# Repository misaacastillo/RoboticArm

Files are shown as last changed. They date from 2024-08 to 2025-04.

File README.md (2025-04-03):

# ROBOTIC ARM

“Robotic Arm” es un brazo robotico el cual cuenta con un modelo dummy de menores dimensiones.
Este modelo copia tendrá una conexión entre sus potenciómetros y los servomotores ubicados en el modelo principal.
Al mover con la mano las 4 articulaciones del modelo dummy provocará que el modelo original se mueva por su cuenta y en sincronía. 
Además el modelo dummy contará con un botón en el extremo superior del brazo, el cual al ser presionado, accionará la pinza ubicada en el extremo superior del modelo original. 

## BRAZO PRINCIPAL:

Robotic arm original

## MODELO DUMMY:

Robotic Arm dummy

## Contacto
### Misael Castillo
* 📷 Instagram: [@misaacas](https://www.instagram.com/misaacas/)
* 📧 Mail: misacastillo08@gmail.com
* 🏆 LinkedIn: [Castillo Misael](https://www.linkedin.com/in/misael-castillo-0a52a1314/)
* 🌐 Github: [misaacastillo](https://github.com/misaacastillo)

## 📜 Licencia

Este proyecto está licenciado bajo la [MIT License](LICENSE).  
© 2024 Robotic Arm By Misael Castilo

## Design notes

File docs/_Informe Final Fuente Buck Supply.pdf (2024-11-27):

EEST N°7 - Computadoras y Sistemas de Control - Profesor Carlassara Fabrizio

## ANTEPROYECTO DE “TÍTULO DEL PROYECTO”

Integrante 1: Castillo Misael

Integrante 2: Bianco Tomas

Integrante 3: Somoza Juan Cruz

Integrante 4: Ramirez Santino

## 1. INTRODUCCIÓN

Este proyecto consiste en el diseño y desarrollo de una fuente de alimentación reductora tipo buck, capaz de transformar una entrada de 220V AC en una salida regulada de 5V DC a 6A. Su diseño incluye etapas de protección, rectificación y regulación, controladas por un microcontrolador RP2040. Esta fuente garantiza una salida estable y eficiente, adecuada para alimentar dispositivos electrónicos que requieren un suministro constante de energía.
El sistema está diseñado para alimentar un brazo robótico que replica movimientos de forma precisa. El brazo principal, equipado con servos en sus articulaciones, se sincroniza con un brazo más pequeño mediante potenciómetros, permitiendo que este último actúe como controlador manual. De esta forma, el proyecto combina una fuente de alimentación confiable con un sistema de robótica interactiva que puede aplicarse en diversas áreas tecnológicas y educativas.

## 2. MARCO DE APLICACIÓN

El marco de aplicación de este proyecto abarca diversas áreas relacionadas con la robótica, la automatización y la electrónica de control. Algunas de las principales áreas o campos en los que podría utilizarse son:

1. Robótica Industrial: Este diseño podría ser utilizado para el control preciso de brazos robóticos en líneas de ensamblaje o procesos automatizados en fábricas, donde la repetición exacta de
movimientos es crucial.
2. Prototipos de Robots
Asistenciales: El brazo robótico replicador puede servir como base para dispositivos en áreas médicas o de rehabilitación, como prótesis robóticas o exoesqueletos, donde es necesario sincronizar
movimientos entre dispositivos.
3. Educación y Capacitación: Este sistema puede ser utilizado en instituciones educativas como herramienta para enseñar
conceptos de control de motores, diseño de fuentes de alimentación, y electrónica de potencia.
4. Robótica de precisión: En laboratorios o centros de
investigación, el brazo podría aplicarse en tareas delicadas que requieren replicación exacta de movimientos, como manipulación de muestras o ensamblaje de componentes pequeños.

## 3. DESCRIPCIÓN TÉCNICA

El proyecto consiste en el diseño de una fuente reductora tipo buck que convierte una entrada de 220V AC en una salida regulada de 5V DC a 6A. El circuito incluye una etapa de protección con fusible, varistor y un puente rectificador (KBU6M) que convierte la señal AC en DC, la cual se filtra mediante un condensador para reducir el ripple. La etapa de regulación utiliza un MOSFET (IRF840N) controlado por una señal PWM generada por el microcontrolador RP2040 Zero. Un inductor se lleva una parte de la tensión de entrada y un diodo Schottky (MBR745) para que la corriente tenga un camino cuando el MOSFET se encuentre NO SATURADO, mientras que un condensador adicional filtra la salida, proporcionando un voltaje constante y estable. El MOSFET está protegido por un diodo zener conectado entre gate y source.
El RP2040 ajusta el ciclo de trabajo del PWM tomando una muestra de la salida mediante un divisor resistivo, que es procesada por el ADC y comparada con una referencia. Si el voltaje de salida está por debajo de la referencia, aumenta el ciclo de trabajo; si está por encima, lo reduce, asegurando así una regulación precisa. Además, se incluye una etapa de pre-amplificación con transistores BC548 para garantizar la correcta conmutación del MOSFET. Este diseño busca mantener una salida estable de 5V DC a pesar de variaciones en la carga o en la entrada.
Esta fuente alimenta un brazo robótico que cuenta con 4 servos, uno en cada articulación del brazo principal de mayor dimensión. Además, hay un brazo más pequeño que tiene un potenciómetro en cada articulación, y estos potenciómetros están conectados a las correspondientes articulaciones del brazo grande. Esto permite que al mover manualmente el brazo pequeño, el brazo grande copie fielmente los movimientos, facilitando el control preciso de las articulaciones mediante la relación directa entre los potenciómetros y los servos.

### 3.1 SOBRE EL HARDWARE

A continuación se adjunta un diagrama en bloques para comprender de manera más sencilla la composición del hardware:

- https://github.com/user-attachments/assets/36affe4c-1349-4181-a6b1-dc6996a2df79 (https://github.com/user-attachments/assets/36affe4c-1349-4181-a6b1-dc6996a2df79)

### 3.2 SOBRE EL SOFTWARE

A continuación se adjunta un diagrama en bloques para comprender la logica del código implementado:

- https://github.com/user-attachments/assets/fa563f7c-4881-4cb9-95a1-9199d777e7dc (https://github.com/user-attachments/assets/fa563f7c-4881-4cb9-95a1-9199d777e7dc)

## 4. DIVISIÓN DE TAREAS

### 4.1 INTEGRANTE 1

Hardware y software

### 4.2 INTEGRANTE 2

Hardware

### 4.3 INTEGRANTE 3

Hardware

### 4.4 INTEGRANTE 4

Hardware

## 5. LISTA DE MATERIALES

### 1. Componentes de la etapa de

entrada y protección

- F1: Fusible 6A
- RV1: Varistor
- D1: Puente de diodos rectificadores (KBU6M)
- C2: Condensador de filtrado 450v 100uf

### 2. Componentes de la etapa buck

- Q1: MOSFET IRF840N
- L1: Inductor (12uH)
- D3: Diodo Schottky (MBR745)
- C1: Condensador de salida (25v 330uf)
- D2: Diodo zener para protección del MOSFET (12v 1w)

- R2 y R3: Resistencias (2k2 1/4w - 6k8 1/4w)

### 3. Controlador PWM y disparo del MOSFET

- RP2040 Zero: Microcontrolador
- R1: Resistencia pull-down (valor no especificado)
- Q2 y Q3: Transistores bipolares BC548
- R4, R5, R6, R7: Resistencias asociadas al control del disparo del MOSFET (47omh, 470omh 1komh)
- C3: Condensador de filtrado del transformador (2200uf 16v)
- D4: Diodo rectificador (1N4007)
- Transformador 12v

### 4. Salidas

- Conectores terminales para servos y alimentación (etiquetados como S0, S1, S2, S3, y sus respectivas conexiones GND y Vout).
- Servos MG946r, SG90.

## 6. IMAGENES DE AVANCES

- PCB
https://github.com/user-attachments/assets/a5d8c636-becd-42a4-9ac3-93294eef8 122 (https://github.com/user-attachments/assets/a5d8c636-becd-42a4-9ac3-93294eef8122)
- Esquematico:
https://github.com/user-attachments/assets/1181bec4-19ed-48ac-91b0-94e42b19 c853 (https://github.com/user-attachments/assets/1181bec4-19ed-48ac-91b0-94e42b19c853)
- Avances:
- https://github.com/user-attachments/assets/632c705f-0e87-40a1 -9880-3bf0f9fe2a5b (https://github.com/user-attachments/assets/632c705f-0e87-40a1-9880-3bf0f9fe2a5b)
- https://github.com/user-attachments/assets/e3903cf5-bc35-4578 -b635-476c0d83b1fa (https://github.com/user-attachments/assets/e3903cf5-bc35-4578-b635-476c0d83b1fa)
- https://github.com/user-attachments/assets/97ad6955-29c6-469a -9932-acfbd8ea4d8d (https://github.com/user-attachments/assets/97ad6955-29c6-469a-9932-acfbd8ea4d8d)

## 7. MEDICIONES REALIZADAS

Se realizaron múltiples mediciones para verificar el funcionamiento de la fuente buck. Inicialmente, se colocó un transformador de 35V en la entrada del circuito. El primer paso fue probar el disparo del MOSFET, para lo cual se conectó a tierra (GND) el pin destinado al control PWM del microcontrolador. Durante esta prueba, se verificó que el MOSFET saturaba correctamente, lo que indicaba que estaba funcionando de acuerdo con lo esperado.

Una vez comprobado el correcto funcionamiento del MOSFET, se procedió a cargar el código en el microcontrolador RP2040. La lógica del código consiste en utilizar el ADC para leer un voltaje de la salida del circuito y compararlo con un voltaje de referencia. Si el voltaje de salida estaba por debajo del valor de referencia, el código aumentaba el ciclo de trabajo del PWM para incrementar el voltaje de salida. Por otro lado, si el voltaje de salida supera el valor de referencia, el ciclo de trabajo se reducía para disminuir el voltaje de salida.

Para realizar la práctica y verificar este comportamiento, se utilizó una fuente de laboratorio conectada al ADC del microcontrolador. Mediante la perilla de ajuste fino de la fuente, se variaba el voltaje entre 0V y 3.3V con precisión. Al realizar esta variación, se observó que el voltaje de salida del circuito respondía adecuadamente al ajuste del ciclo de trabajo generado por el microcontrolador.

Sin embargo, se detectó un problema crítico: al saturar el MOSFET, la tensión de entrada aparecía momentáneamente en la salida. Este comportamiento representaba un fallo grave en el diseño de la fuente buck.

## 8. CONCLUSIÓN FINAL

En conclusión, aunque se logró implementar la lógica de control y se verificó su funcionamiento en términos de ajuste de la salida, el problema identificado con la tensión de entrada en la salida durante la saturación del
MOSFET marcó el final del desarrollo de esta fuente buck. A pesar de no poder lograr el correcto funcionamiento de este circuito, durante el proceso se ha podido aprender mucho sobre electrónica de potencia y la implementación de un microcontrolador en este ámbito.

## 9. Repositorio GITHUB

https://github.com/misaacastillo/RoboticArm

## 9. REFERENCIAS

Agregar cualquier referencia que se haya usado durante la investigación o el informe.

[1] Referencia 1. Disponible en: https://datasheets.raspberrypi.com/pico/raspberry-pi -pico-c-sdk.pdf (https://datasheets.raspberrypi.com/pico/raspberry-pi-pico-c-sdk.pdf)
[2] Referencia 2. Disponible en: https://www.youtube.com/watch?v=AIsVlgopqJc&t=480s&ab_channel=BuildSomeStuff (https://www.youtube.com/watch?v=AIsVlgopqJc&t=480s&ab_channel=BuildSomeStuff)
[3] Referencia 3. Disponible en: https://www.academia.edu/11237823/ELECTR%C3

%93NICA_DE_POTENCIA_ELECTR%C3%93NICA _DE_POTENCIA (https://www.academia.edu/11237823/ELECTR%C3%93NICA_DE_POTENCIA_ELECTR%C3%93NICA_DE_POTENCIA)

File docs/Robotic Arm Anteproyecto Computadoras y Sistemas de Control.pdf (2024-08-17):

EEST N°7 - Computadoras y Sistemas de Control - Profesor Carlassara Fabrizio

ANTEPROYECTO DE “ROBOTIC ARM”

Integrante 1: Castillo Misael Integrante 1: correo electrónico: misaelcastillo@impatrq.com Integrante 2: Bianco Tomas Integrante 2: correo electrónico: tomasmartinbianco@impatrq.com Integrante 3: Somoza Juan Cruz Integrante 3: correo electrónico:juancruzarielsomoza@impatrq.com Integrante 4: Tolosa Ramirez Santino Integrante 4: correo electrónico: santinoramireztolosa@impatrq.com

### 1. INTRODUCCIÓN

“Robotic Arm” es un brazo robótico el cual cuenta con un modelo dummy de menores dimensiones. Este modelo copia tendrá una conexión entre sus potenciómetros y los servomotores ubicados en el modelo principal. Al mover con la mano las 4 articulaciones del modelo dummy provocará que el modelo original se mueva por su cuenta y en sincronía. Además el modelo dummy contará con un botón en el extremo superior del brazo, el cual al ser presionado, accionará la pinza ubicada en el extremo superior del modelo original.

### 2. MARCO DE APLICACIÓN

### 2.1 BRAZO ROBÓTICO

Este proyecto tiene una gran variedad de aplicaciones. Una de ellas podría ser en el área de la medicina. En el caso que se presentará un paciente con una enfermedad contagiosa de alto riesgo, se podría instalar el modelo original en un cuarto aislado y el modelo dummy en el exterior. Así los enfermeros o médicos podrían atender a las necesidades del paciente sin contagiarse.
También este brazo robótico podría participar en cirugías asistidas.
Otro campo de aplicación posible es en la educación. Se podría instalar el modelo principal en el pizarrón de la clase y el modelo dummy en el escritorio del profesor. Este podría escribir en el pizarrón con mayor comodidad y mayor eficiencia.

### 2.2 FUENTE TIPO SWITCHING

Las fuentes de alimentación tipo switching o fuentes conmutadas son muy versátiles y se utilizan en una variedad de aplicaciones debido a su alta eficiencia, tamaño compacto y capacidad para manejar una amplia gama de voltaje de entrada. Estas mismas se pueden encontrar en:
1. dispositivos electrónicos
Son esenciales en una amplia gama de dispositivos. como por ejemplo computadoras, teléfonos y sistemas de comunicación
2. aplicaciones industriales y comerciales
3. dispositivos portátiles y electrónica de consumo
Son compactas y ligeras, lo que las hace ideal para aplicaciones en donde el espacio es limitado
4. máquinas y procesos

### 3. DESCRIPCIÓN TÉCNICA

Se debe realizar una descripción de cada uno de los componentes que se planea usar para este proyecto. Incluir qué variables se estarán monitoreando mediante el sistema de control.

1- Fuente conmutada:

Una fuente conmutada usa la señal de control para variar el ancho de pulso, tomando de la alimentación solamente la energía requerida por la carga.

2- Modelo Dummy:
Este es un modelo a escala del brazo robótico principal. Tiene 4 articulaciones que pueden moverse manualmente. Cada articulación está equipada con un potenciómetro que mide el ángulo de la articulación.

3- Potenciómetros:
Estos son sensores que miden el ángulo de las articulaciones en el modelo dummy. Cuando mueves una articulación en el modelo dummy, el potenciómetro correspondiente produce una señal eléctrica proporcional al ángulo de la articulación.

4- Servomotores:
Estos están ubicados en el brazo robótico principal. Cada servomotor está conectado a un potenciómetro en el modelo dummy. Cuando el potenciómetro detecta un cambio en el ángulo de una articulación, envía una señal al servomotor correspondiente para mover la articulación en el brazo robótico principal.

5- Pinza:
Está ubicada en el extremo superior del brazo robótico principal. Se activa cuando se presiona un botón en el extremo superior del modelo dummy.

Las variables que se estarán monitoreando incluyen:

1- Ángulos de las articulaciones: Estos son medidos por los potenciómetros en el modelo dummy. Estos ángulos son las variables de entrada para el sistema de control.

2- Posición de la pinza: Esta es una variable binaria que indica si la pinza está abierta o cerrada. Se activa cuando se presiona el botón en el modelo dummy

3- fuente conmutada: En el caso de la fuente conmutada, utiliza el sistema de comunicación denominado “modulación por ancho de pulso” (PWM) y la variable a monitorear es:

- Tensión de salida (Vout): Es fundamental monitorear esta variable para garantizar que la tensión de salida se mantenga dentro de los límites especificados. Esta variable será introducida por una entrada del microcontrolador ADC (analog to digital converter) y será monitoreada por nuestro microcontrolador. Cuando el ADC muestre una lectura del voltaje de salida errónea automáticamente el microcontrolador adaptará el ancho de pulso del PWM para corregir la tensión de salida

### 3.1 SOBRE EL HARDWARE

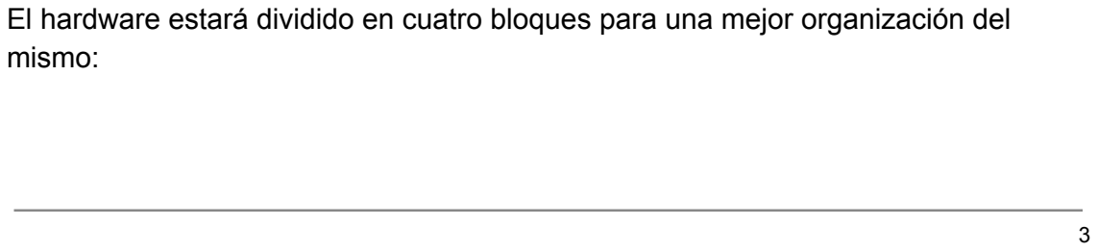
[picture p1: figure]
mismo:

El hardware estará dividido en cuatro bloques para una mejor organización del

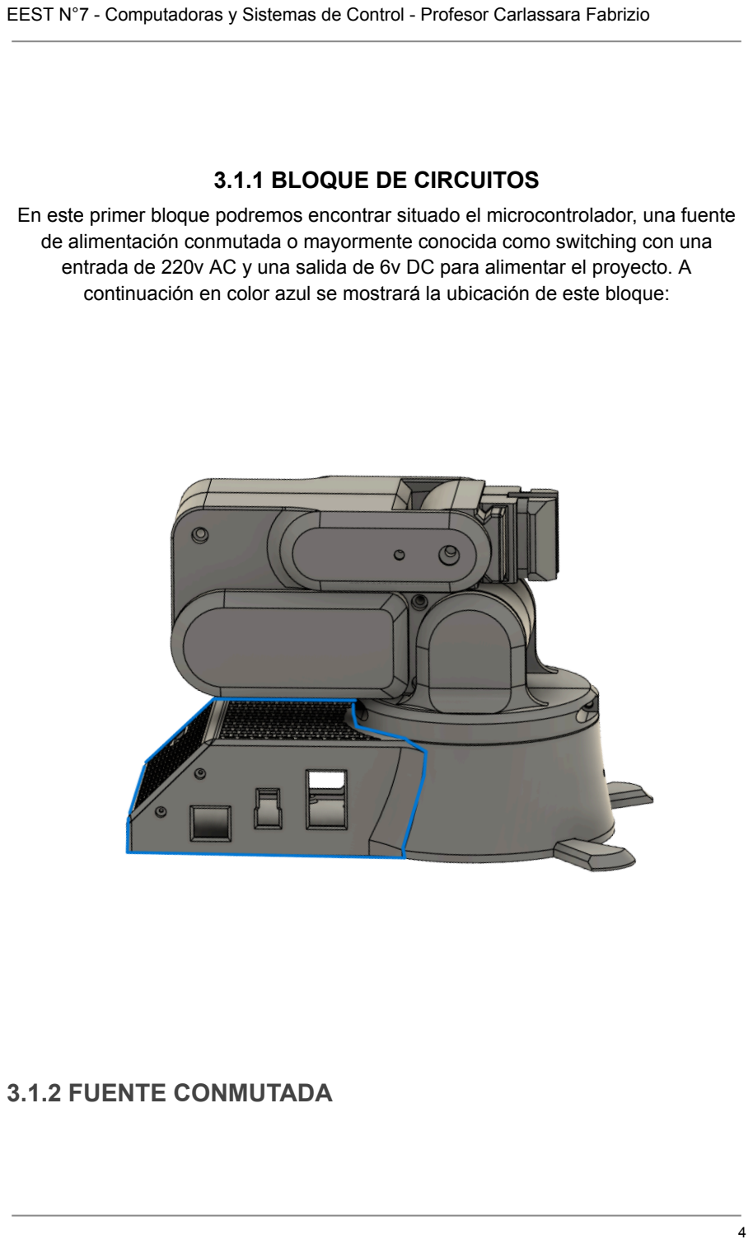
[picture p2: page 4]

### 3.1.1 BLOQUE DE CIRCUITOS

En este primer bloque podremos encontrar situado el microcontrolador, una fuente de alimentación conmutada o mayormente conocida como switching con una entrada de 220v AC y una salida de 6v DC para alimentar el proyecto. A continuación en color azul se mostrará la ubicación de este bloque:

### 3.1.2 FUENTE CONMUTADA

- Entrada Ac
- Puente rectificador: Un puente rectificador consta de cuatro diodos conectados en una configuración específica. En una disposición típica, dos diodos se conectan en serie en una dirección, y otros dos diodos se conectan en serie en la dirección opuesta. Esto crea una estructura en forma de puente. La corriente alterna (CA) de la red eléctrica se rectifica para convertirla en corriente continua (CC)
- Condensador: Amortigua la corriente pulsante para convertirla en corriente continua con un valor estable
- Conmutación: Un dispositivo semiconductor, que generalmente es un MOSFET, se utiliza para alternar rápidamente entre un estado de conducción completo (encendido) y un estado de corte completo (apagado). Este proceso de conmutación se controla para regular la cantidad de energía que se entrega a la carga.
- Controlador: Activa y desactiva el transistor. También controla al circuito de corrección del factor de potencia. Además, mide la tensión de salida de la fuente, y modifica la señal entregada al transistor, para regular la tensión y mantener estable la salida
- Bobina: Durante el ciclo de conmutación, la energía almacenada en un inductor se transfiere a la carga. La relación entre el tiempo que el dispositivo está encendido y apagado controla la cantidad de energía entregada.
- Diodo: Convierte la corriente alterna del transformador a corriente pulsante.
- Filtro: Convierte la corriente pulsante en continua.

### 3.1.3 BLOQUE ROTOR 180’

En este bloque estará ubicado un servomotor el cual le dará la capacidad a la mano robótica de poder realizar un giro de 360°. A continuación en color rojo se mostrará la ubicación de este bloque:

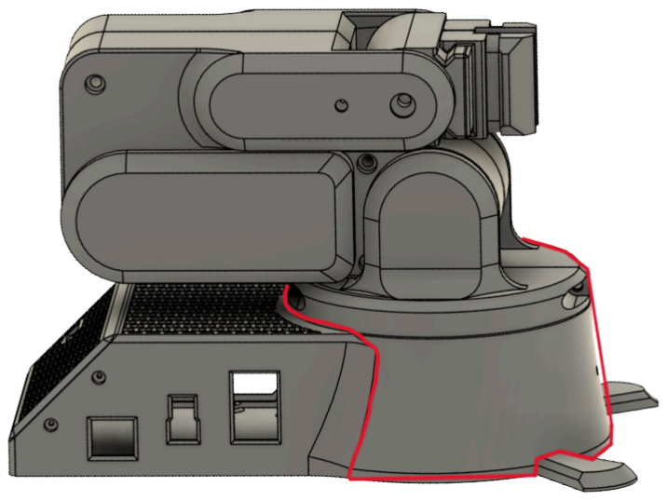
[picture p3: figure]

### 3.1.4 BLOQUE ARTICULACIONES

En este bloque se encuentran los servo motores encargados de articular el brazo robótico. A continuación en color naranja se mostrará la ubicación de este bloque:

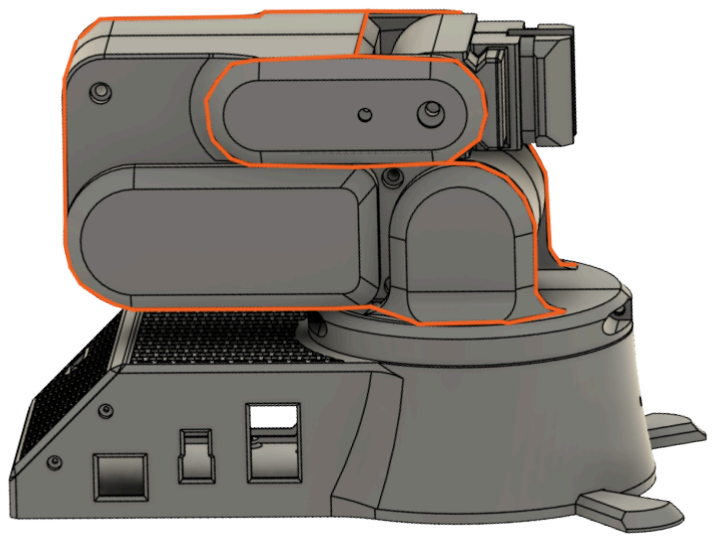
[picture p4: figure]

### 3.1.5 BLOQUE PINZA

Por último en este bloque se encontrará el servo encargado de abrir y cerrar esta pinza. A continuación en color naranja se mostrará la ubicación de este bloque:

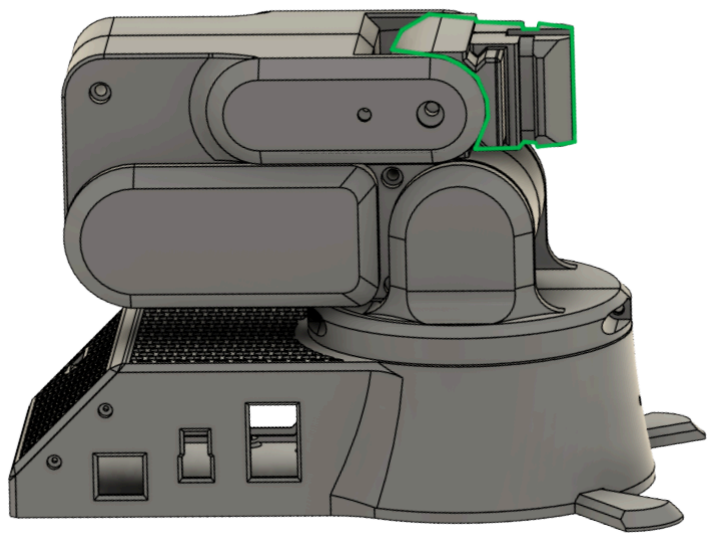
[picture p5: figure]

ACLARACIÓN: ESTE ES UN BOCETO DE DISEÑO, A FUTURO SE REALIZARÁN MODIFICACIONES PARA MEJORAR SU ESTÉTICA Y OPTIMIZAR LA DISTRIBUCIÓN DE CIRCUITOS.

### 3.2 SOBRE EL SOFTWARE

- Lectura de datos: Implementar un código que lea los datos de los potenciómetros en el modelo dummy. Estos datos representan los ángulos de las articulaciones y se utilizarán para controlar los servomotores en el brazo robótico principal.
- Control de servomotores: Desarrollar un algoritmo que tome los datos de los potenciómetros y los convierta en señales de control para los servomotores. Este algoritmo debe asegurarse de que los movimientos del brazo robótico principal estén sincronizados con los del modelo dummy.
- Control de la pinza: Implementar un código que detecte cuando se presiona el botón en el modelo dummy y active la pinza en el brazo robótico principal.
- Pruebas y depuración: Realizar pruebas exhaustivas para asegurarse de que el software funciona correctamente. Esto incluirá pruebas unitarias de cada componente individualmente, así como pruebas de integración para verificar que todos los componentes funcionen juntos como se espera.

### 4. DIVISIÓN DE TAREAS

Detallar las tareas asignadas a cada integrante del equipo.

### 4.1 INTEGRANTE 1

- software (codigo), estructura en 3D

### 4.2 INTEGRANTE 2

- software (codigo)

### 4.3 INTEGRANTE 3

- Hardware (conexiones) , ensamblaje

### 4.4 INTEGRANTE 4

- Hardware (alimentación)

### 5. LISTA DE MATERIALES

A-Mg946r Servo Motor x 4
B-Mini Servo Tower Pro Sg90 x1 C-Fuente switching
D-Impresiones en 3D
E-Potenciómetros 10k x3
F-Raspberry pi pico

### 5. REFERENCIAS

Agregar cualquier referencia que se haya usado durante la investigación o el informe.

[1] Referencia 1. Disponible en: https://www.youtube.com/watch?v=5toNqaGsGYs&ab_channel=BuildSomeStuff

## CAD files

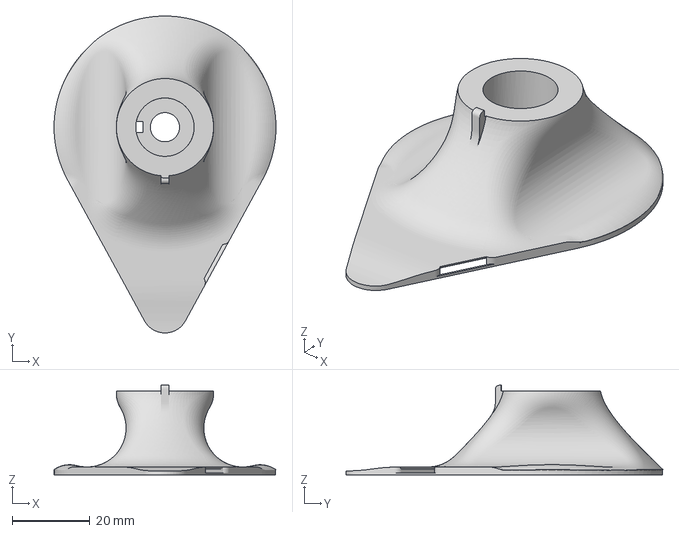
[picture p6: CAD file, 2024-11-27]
mechanical/Piezas 3D 2/Cuerpo1.3mf
57.0 x 81.4 x 23.0 mm

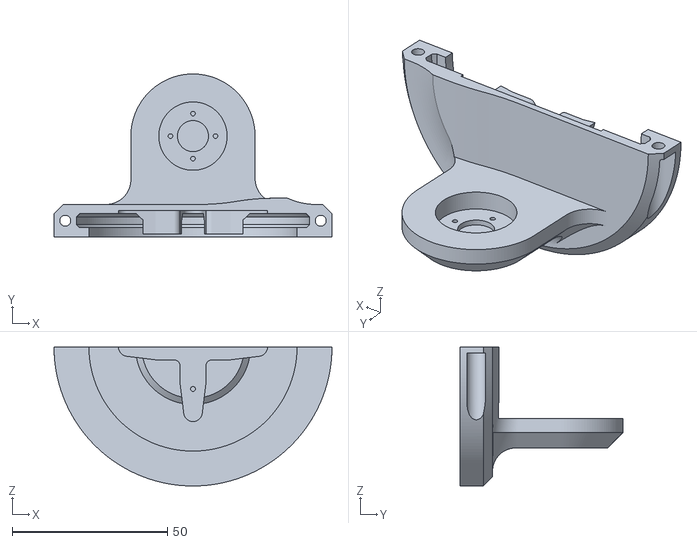
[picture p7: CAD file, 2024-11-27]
mechanical/Piezas 3D/Cuerpo7.stl
89.5 x 52.5 x 44.7

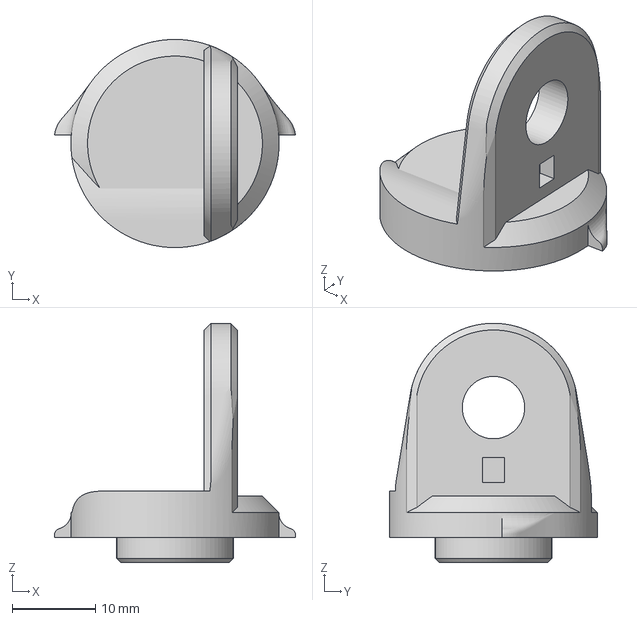
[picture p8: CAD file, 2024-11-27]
mechanical/Piezas 3D 2/Cuerpo2.3mf
28.9 x 25.0 x 28.7 mm

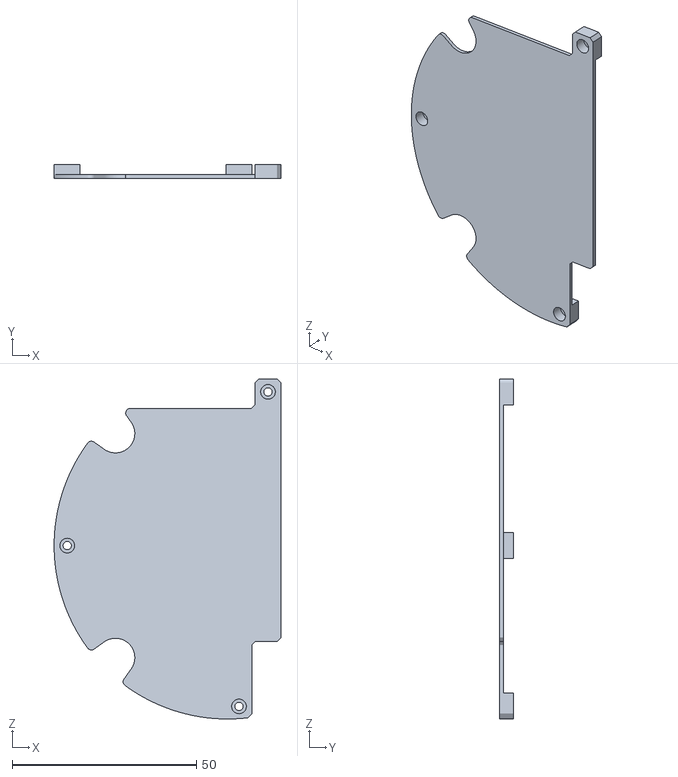
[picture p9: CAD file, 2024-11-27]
mechanical/Piezas 3D/Cuerpo12.stl
61.6 x 3.75 x 92.4

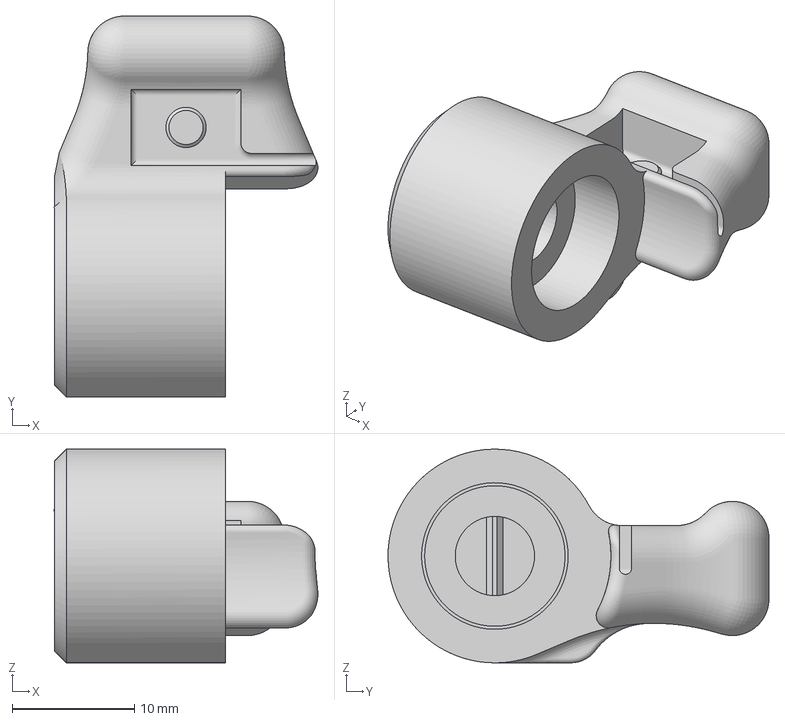
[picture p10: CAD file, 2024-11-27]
mechanical/Piezas 3D 2/Cuerpo5.3mf
21.6 x 31.2 x 17.5 mm

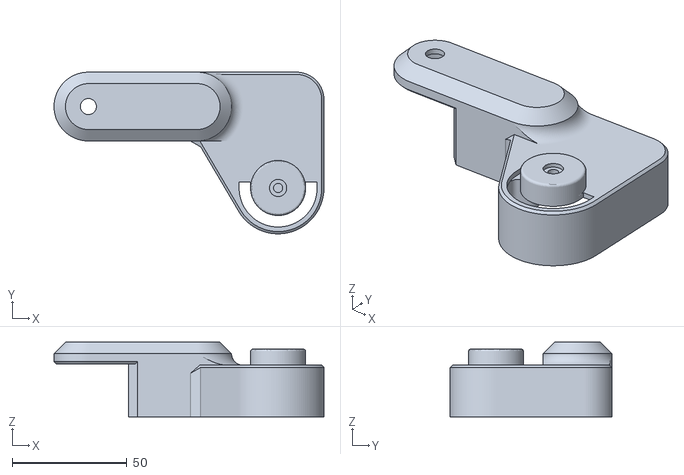
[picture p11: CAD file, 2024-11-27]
mechanical/Piezas 3D/Cuerpo2.stl
117.7 x 70.5 x 32.5

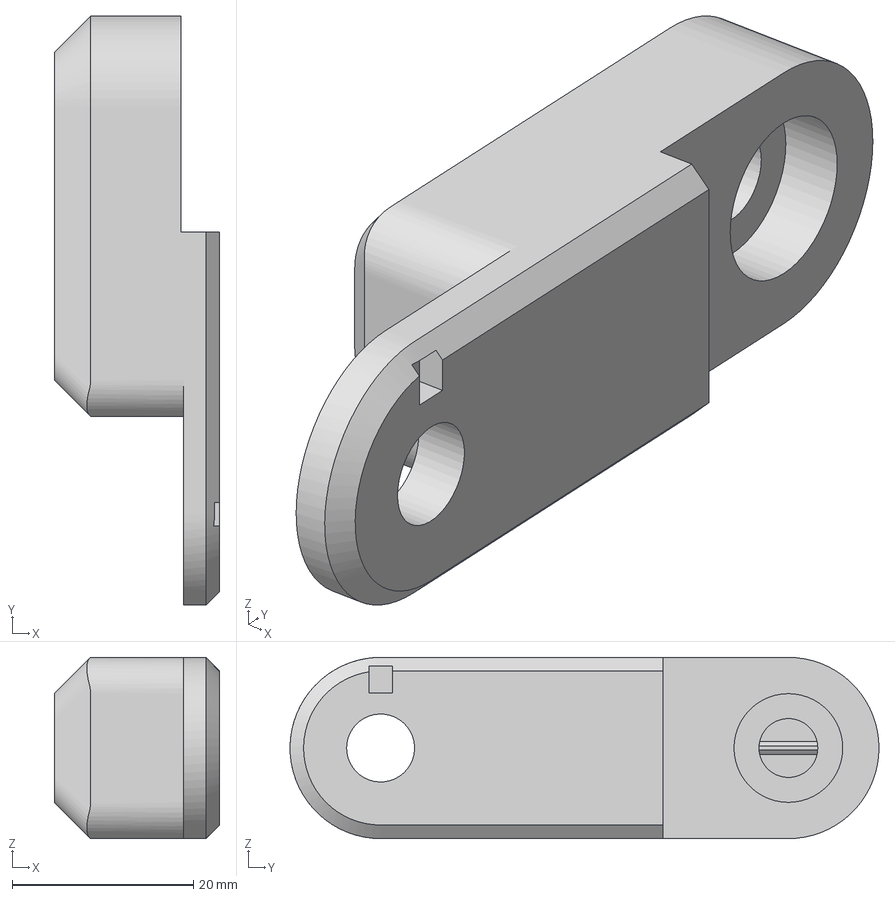
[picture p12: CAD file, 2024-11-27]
mechanical/Piezas 3D 2/Cuerpo3.3mf
18.2 x 65.0 x 20.0 mm

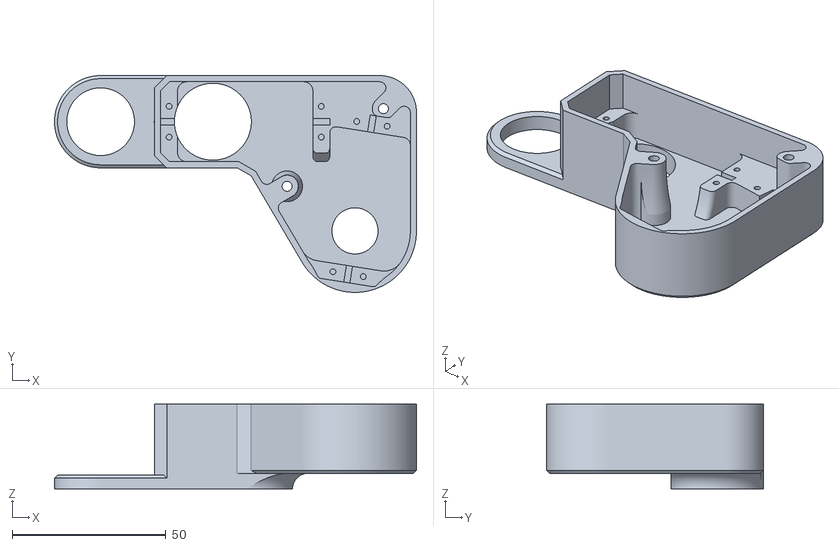
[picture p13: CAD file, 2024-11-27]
mechanical/Piezas 3D/Cuerpo8.stl
117.7 x 70.5 x 27.5

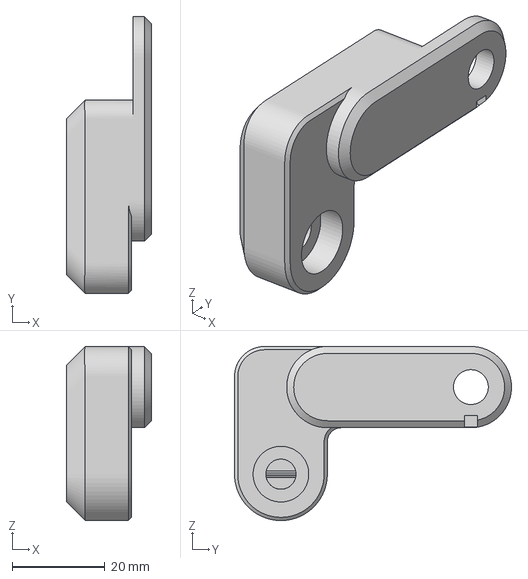
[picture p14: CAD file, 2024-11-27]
mechanical/Piezas 3D 2/Cuerpo4.3mf
18.2 x 59.6 x 37.5 mm

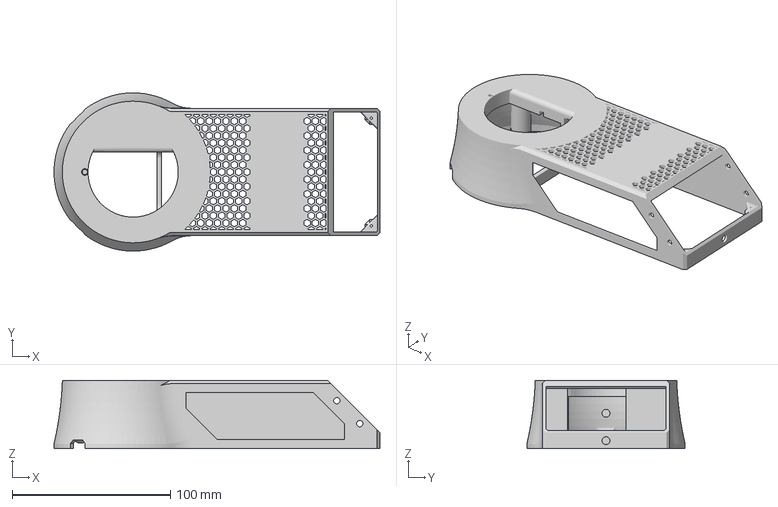
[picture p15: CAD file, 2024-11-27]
mechanical/Piezas 3D/Estructura inf fuente.3mf
206.0 x 100.0 x 43.0 mm

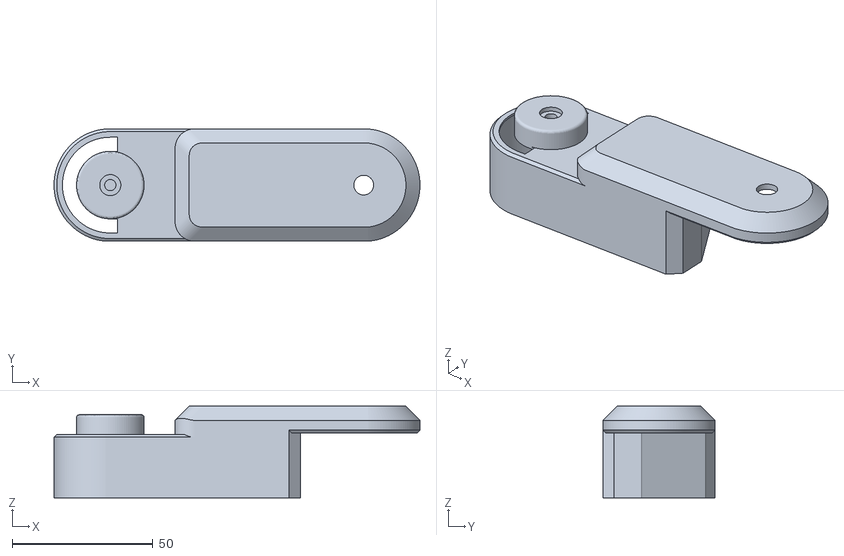
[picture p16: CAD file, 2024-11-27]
mechanical/Piezas 3D/Cuerpo1.stl
130.0 x 39.9 x 32.5

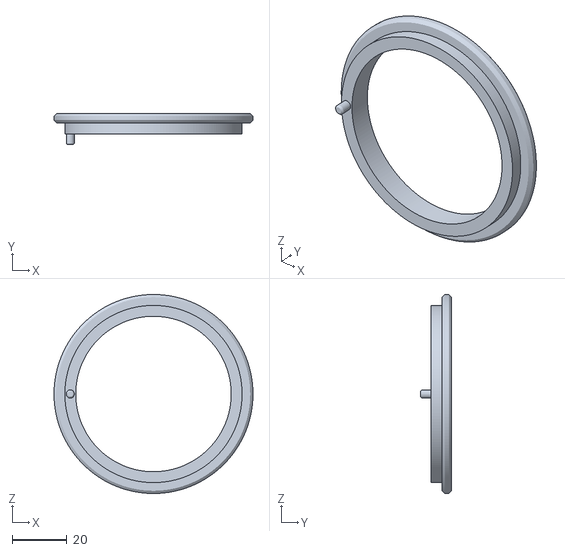
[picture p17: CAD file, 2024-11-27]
mechanical/Piezas 3D/Cuerpo6.stl
73.0 x 11.5 x 73.0

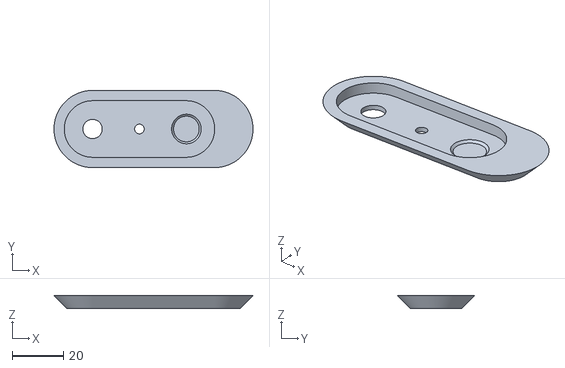
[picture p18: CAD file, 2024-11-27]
mechanical/Piezas 3D/Cuerpo3.stl
77.4 x 30.0 x 5.00

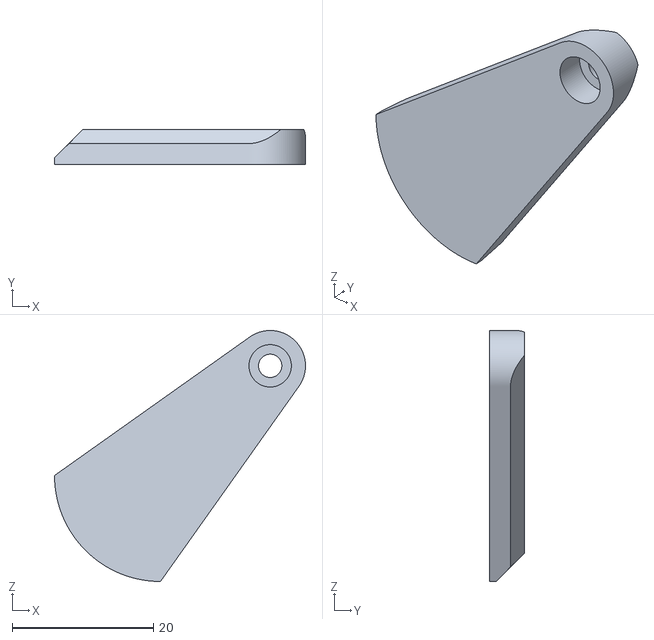
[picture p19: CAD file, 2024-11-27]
mechanical/Piezas 3D/Cuerpo16.stl
35.5 x 5.00 x 35.5

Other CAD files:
mechanical/Piezas 3D/Cuerpo21.stl
mechanical/Piezas 3D/Cuerpo18.stl
mechanical/Piezas 3D/tapa inferior.3mf
mechanical/Piezas 3D/Cuerpo20.stl
mechanical/Piezas 3D/Cuerpo11.stl
mechanical/Piezas 3D/Cuerpo15.stl
mechanical/Piezas 3D/Cuerpo19.stl
mechanical/Piezas 3D/Cuerpo4 AR-4.3mf
mechanical/Piezas 3D/Cuerpo5.stl
mechanical/Piezas 3D/Cuerpo9.stl
mechanical/Piezas 3D/Robotic Arm Proyect.3mf

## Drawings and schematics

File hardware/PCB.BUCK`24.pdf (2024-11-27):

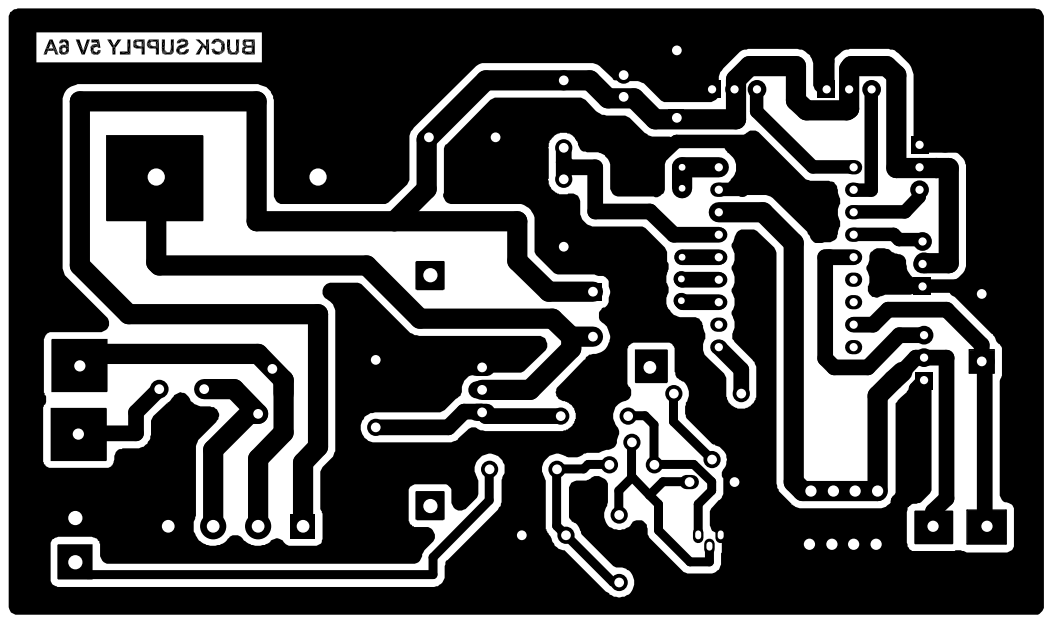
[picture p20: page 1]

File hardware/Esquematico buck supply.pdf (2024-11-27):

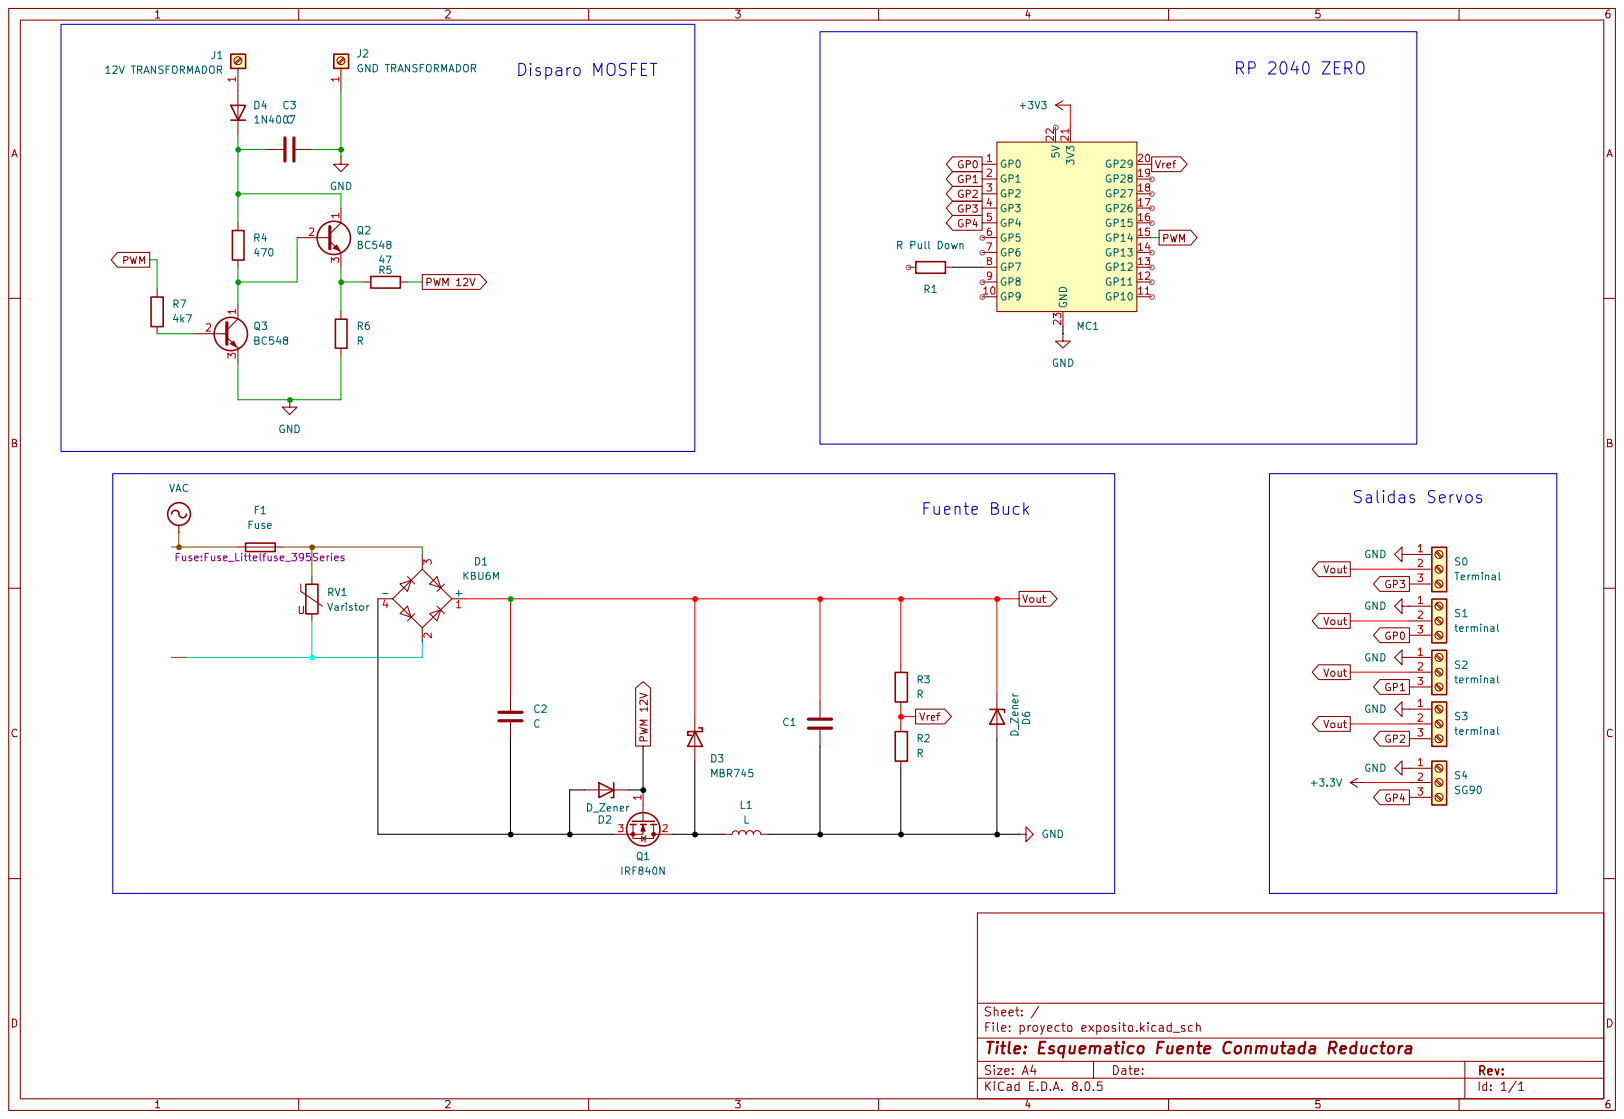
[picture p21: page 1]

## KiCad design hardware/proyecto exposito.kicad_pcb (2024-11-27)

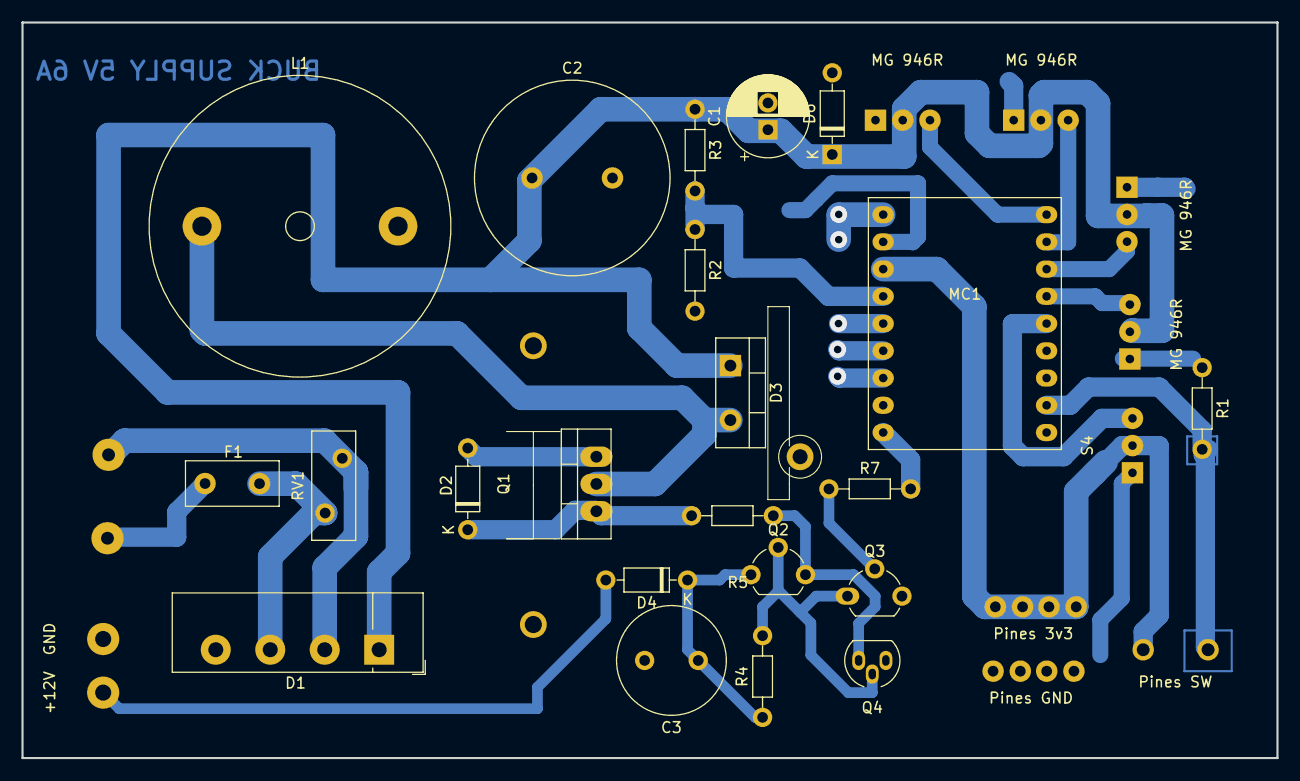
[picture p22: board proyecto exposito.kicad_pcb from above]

Board: 2 copper layers, 117.1 x 68.6 mm, 30 parts (0 on the bottom side), 19 nets.

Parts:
C1: C; CP_Radial_D7.5mm_P2.50mm
C2: C; C_Radial_D18.0mm_H35.5mm_P7.50mm
C3: C; C_Radial_D10.0mm_H20.0mm_P5.00mm
D1: KBU6M; Diode_Bridge_Vishay_KBU
D2, D6: D_Zener; D_DO-35_SOD27_P7.62mm_Horizontal
D3: MBR745; TO-220-2_Vertical
D4: 1N4007; D_DO-35_SOD27_P7.62mm_Horizontal
F1: Fuse; Fuse_Littelfuse_395Series
L1: L; L_Radial_D27.9mm_P18.29mm_Vishay_IHB-3
MC1: RP2040-Zero
Pines 3v3: Terminal; TerminalBlock_Xinya_XY308-2.54-3P_1x03_P2.54mm_Horizontal
Pines GND: Terminal; TerminalBlock_Xinya_XY308-2.54-3P_1x03_P2.54mm_Horizontal
Q1: IRF840N; TO-220-3_Vertical
Q2, Q3: BC548; TO-92_Wide
Q4: BC558; TO-92_HandSolder
R1: R Pull Down; R_Axial_DIN0204_L3.6mm_D1.6mm_P7.62mm_Horizontal
R2, R3: R; R_Axial_DIN0204_L3.6mm_D1.6mm_P7.62mm_Horizontal
R4: 470; R_Axial_DIN0204_L3.6mm_D1.6mm_P7.62mm_Horizontal
R5: 47; R_Axial_DIN0204_L3.6mm_D1.6mm_P7.62mm_Horizontal
R7: 4k7; R_Axial_DIN0204_L3.6mm_D1.6mm_P7.62mm_Horizontal
RV1: Varistor; Fuse_BelFuse_0ZRE0016FF_L9.9mm_W3.8mm
S0: Terminal; TerminalBlock_Xinya_XY308-2.54-3P_1x03_P2.54mm_Horizontal
S1, S2, S3: terminal; TerminalBlock_Xinya_XY308-2.54-3P_1x03_P2.54mm_Horizontal
S4: SG90; TerminalBlock_Xinya_XY308-2.54-3P_1x03_P2.54mm_Horizontal
pines: Terminal; TerminalBlock_Xinya_XY308-2.54-3P_1x03_P2.54mm_Horizontal

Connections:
+3V3: MC1.21 (3V3), Pines 3v3.1, pines.1
GND: C1.2, C2.2, C3.2, D1.4 (-), D2.2 (A), D6.2 (A), L1.2, MC1.23 (GND), Pines GND.1, Q1.3 (S), Q3.3 (E), Q4.1 (C), R1.1, R2.2, S0.1, S1.1, S2.1, S3.1, S4.1
GP0: MC1.1 (GP0), S1.3
GP1: MC1.2 (GP1), S2.3
GP2: MC1.3 (GP2), S3.3
GP3: MC1.4 (GP3), S0.3
GP4: MC1.5 (GP4), S4.3
unnamed: D1.2, RV1.2
unnamed: D1.3, F1.2, RV1.1
unnamed: D3.2 (A), L1.1, Q1.2 (D)
unnamed: C3.1, D4.1 (K), Q2.1 (C), R4.1
unnamed: MC1.8 (GP7), R1.2
unnamed: Q2.2 (B), Q3.1 (C), Q4.2 (B), R4.2
unnamed: Q2.3 (E), Q4.3 (E), R5.1
unnamed: Q3.2 (B), R7.1
PWM: MC1.15 (GP14), R7.2
PWM 12V: D2.1 (K), Q1.1 (G), R5.2
Vout: C1.1, C2.1, D1.1 (+), D3.1 (K), D6.1 (K), R3.1, S0.2, S1.2, S2.2, S3.2
Vref: MC1.20 (GP29), R2.1, R3.2

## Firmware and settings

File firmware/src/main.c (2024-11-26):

#include <stdio.h>
#include "pico/stdlib.h"
#include "servo_pwm.h"
#include "adc_input.h"
#include "proyect.h"
#include "servo_pwm.h"

int main() {
    stdio_init_all();
    
    // Inicializar los pines de los servos
    servo_init(SERVO_PIN1);
    servo_init(SERVO_PIN2);
    servo_init(SERVO_PIN3);
    servo_init(SERVO_PIN4);
    servo_init(SERVO_PIN5);

    gate_init(GATE_PIN);

    // Inicializar los pines de los potenciómetros
    uint8_t adc_pins[] = {POT_PIN1, POT_PIN2, POT_PIN3, POT_PIN4};
    adc_init_inputs(adc_pins, 4);

    while (true) {
        // Lee y convierte el valor de cada potenciómetro, y ajusta el servo correspondiente
        set_servo_angle(SERVO_PIN1, adc_to_angle(adc_read_value(0)));
        set_servo_angle(SERVO_PIN2, adc_to_angle(adc_read_value(1)));
        set_servo_angle(SERVO_PIN3, adc_to_angle(adc_read_value(2)));
        set_servo_angle(SERVO_PIN4, adc_to_angle(adc_read_value(3)));

        sleep_ms(20); // Pequeño retardo para estabilizar el movimiento del servo

        if (SW_PIN == 0) {

            set_servo_angle(SERVO_PIN4, 270);

    }

    return 0;
}

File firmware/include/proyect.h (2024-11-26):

#include "pico/stdlib.h"
#include <stdio.h>

#define SERVO_PIN1 0
#define SERVO_PIN2 1
#define SERVO_PIN3 2
#define SERVO_PIN4 3
#define SERVO_PIN5 4
#define POT_PIN1 26
#define POT_PIN2 27
#define POT_PIN3 28
#define POT_PIN4 29
#define GATE_PIN 14
#define SW_PIN 7

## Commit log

2024-11-26 Create PCB
2024-11-26 Create PCB & ESQUEMATICO
2024-11-26 Update pcb
2024-11-27 Create Controller STL files
